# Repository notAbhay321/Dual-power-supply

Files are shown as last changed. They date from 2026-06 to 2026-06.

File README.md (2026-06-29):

# ESP32 Smart Automation — Regulated AC to DC Multi-Voltage Power Supply

A custom-designed regulated power supply that converts **230V AC mains** into stable **5V and 3.3V DC** outputs for ESP32-based smart automation systems (water tank management, irrigation control, etc.).

> **Total BOM Cost: ~₹583** | **Efficiency: 88–90%** | **Ripple: <30 mV**

---

## Hardware

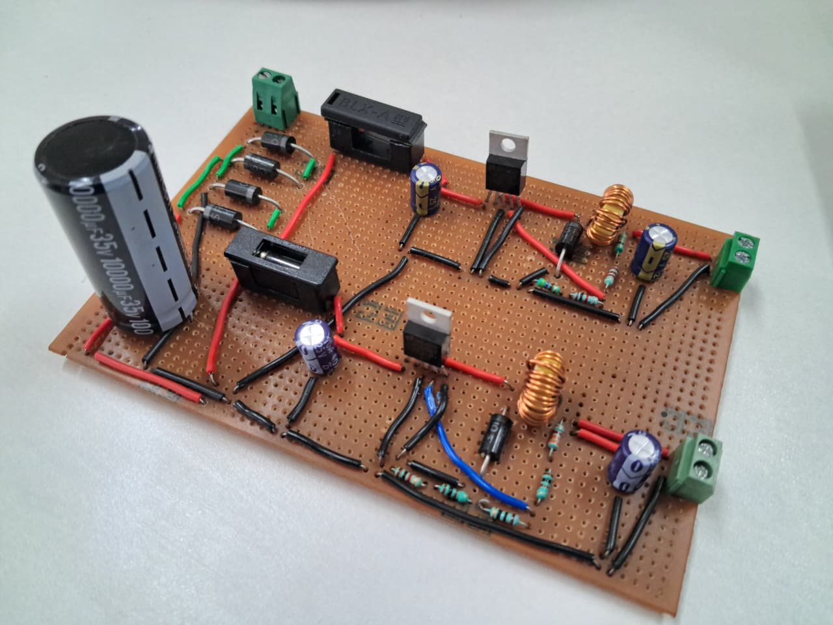
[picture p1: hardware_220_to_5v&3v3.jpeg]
Hardware PCB


*Assembled prototype — 230V AC to 5V & 3.3V regulated DC*

---

## Simulation Results

| 5V Output Rail | 3.3V Output Rail |
|:---:|:---:|
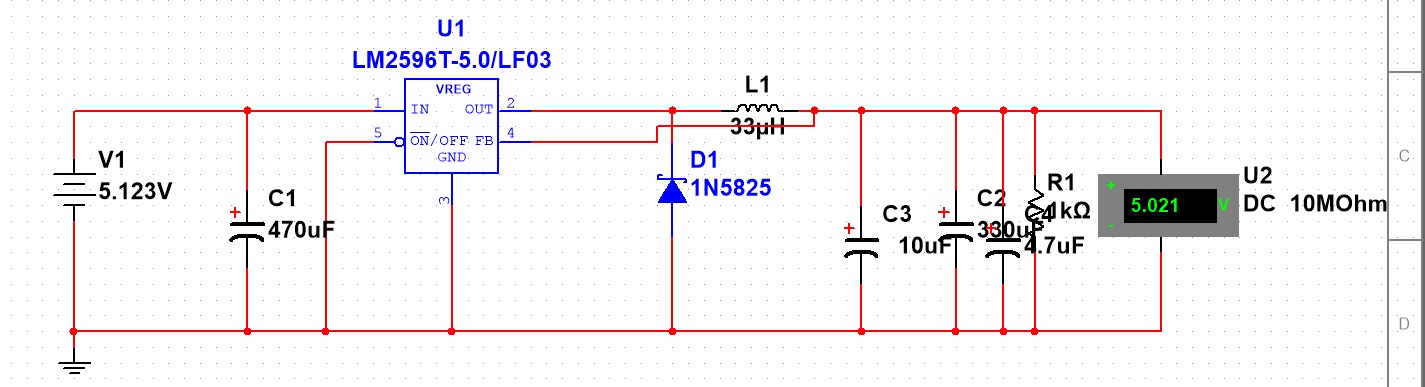
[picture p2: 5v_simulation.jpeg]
5V Simulation
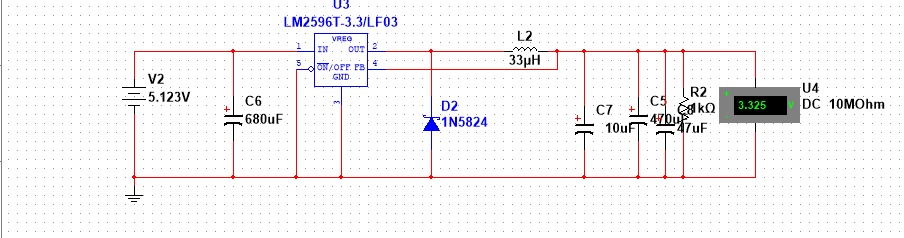
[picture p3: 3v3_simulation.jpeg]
3.3V Simulation
|  |  |

---

## Demo Video

▶️ [`output_video_5v and 3.3v.mp4`](output_video_5v%20and%203.3v.mp4) — Live measurement of both regulated outputs under load.

---

## Why This Project Exists

Off-the-shelf USB adapters and chargers fail in 24/7 automation scenarios because:

- They provide only one voltage rail
- They introduce electrical noise → sensors misread
- Voltage sags during ESP32 WiFi transmission → random controller resets
- They lack proper isolation from 230V AC (safety risk outdoors)

This project builds a **dedicated dual-rail power supply** that separates:
- **5V rail** → Relay modules, ultrasonic sensors
- **3.3V rail** → ESP32 controller, soil moisture sensors

---

## Key Specifications

| Parameter | Value |
|---|---|
| AC Input | 230V, 50Hz |
| DC Output 1 | 5V @ 2A |
| DC Output 2 | 3.3V @ 1A |
| Ripple Voltage | < 30 mV (3.3V rail) |
| Regulation IC | LM2596-ADJ (×2) |
| Efficiency | 88–90% |
| Isolation | Transformer-based galvanic isolation |

---

## System Overview

```
230V AC → Step-Down Transformer → Bridge Rectifier (SR560)
       → Filter Capacitors (10,000 µF)
       → LM2596 Buck #1 → 5V Rail  → Relays, Ultrasonic Sensor
       → LM2596 Buck #2 → 3.3V Rail → ESP32, Soil Moisture Sensor
```
### Full Block Diagram and Flowchart

<p align="center">
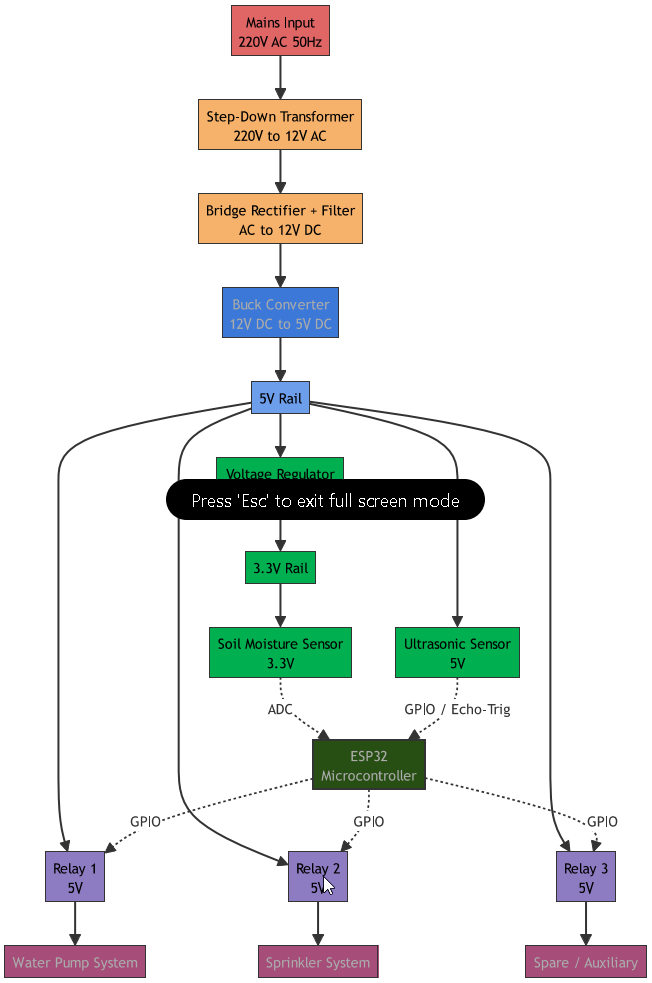
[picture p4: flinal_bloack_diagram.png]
Block diagram
  
</p>
---

## Repository Structure

```
esp32-power-supply/
├── README.md                         ← You are here
│
├── 5v_simulation.jpeg                ← 5V buck converter simulation output
├── 3v3_simulation.jpeg               ← 3.3V buck converter simulation output
├── hardware_220_to_5v&3v3.jpeg       ← Hardware prototype photo
├── output_video_5v and 3.3v.mp4      ← Live demo video
│
├── PowerSupply.ms14                  ← Main Multisim simulation (full circuit)
├── transformer_220v_9v.ms14          ← Transformer stage simulation
├── 220v_to_3v3_short_ckt_protection.ms14  ← Short circuit protection sim
│
├── ki_cad_pcb_power_supply/          ← KiCad PCB design files
├── datasheet/                        ← Component datasheets (LM2596, SR560, etc.)
│
├── docs/
│   ├── 01-introduction.md            ← Problem statement, motivation, objectives
│   ├── 02-literature-survey.md       ← Power supply topology review
│   ├── 03-system-design.md           ← Block diagram, flowchart, design decisions
│   ├── 04-calculations.md            ← Full component-level math
│   ├── 05-results.md                 ← Simulation + hardware results
│   └── 06-future-scope.md            ← Planned improvements
│
├── hardware/
│   ├── bom.md                        ← Bill of Materials with costs
│   └── component-selection.md        ← Why each component was chosen
│
├── simulation/
│   └── README.md                     ← How to open and run the .ms14 files
│
├── images/                           ← Additional diagrams and screenshots
├── LICENSE
```

---

## Quick Results

| Test Point | Measured Value |
|---|---|
| Transformer Secondary Output | ~14.1V AC |
| Rectified DC (after filter) | ~16V DC |
| Buck Converter Output 1 | **5.02V DC** |
| Buck Converter Output 2 | **3.31V DC** |
| Ripple (3.3V rail) | **< 30 mV** |
| Max Load (5V rail) | 2A stable |
| ESP32 WiFi peak handling | 250–500 mA, no resets |

---

## PCB Design

KiCad schematic and PCB layout files are in [`ki_cad_pcb_power_supply/`](ki_cad_pcb_power_supply/).
Open with **KiCad 9.0+**.

---

## Simulation Files

All simulations were built in **NI Multisim**. Open the `.ms14` files in Multisim 14+:

| File | What It Simulates |
|---|---|
| [`PowerSupply.ms14`](PowerSupply.ms14) | Full circuit — transformer → rectifier → both buck converters |
| [`transformer_220v_9v.ms14`](transformer_220v_9v.ms14) | Transformer stage only (220V → 9V AC) |
| [`220v_to_3v3_short_ckt_protection.ms14`](220v_to_3v3_short_ckt_protection.ms14) | Short circuit protection on 3.3V rail |

See [`simulation/README.md`](simulation/README.md) for setup instructions.

---

## License

MIT License — see [`LICENSE`](LICENSE)

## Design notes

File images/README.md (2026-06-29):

# Images

Additional diagrams and reference screenshots.

---

## What's in the Root (not this folder)

The main project visuals are stored at the **repository root** for easy GitHub rendering:

| File | Description |
|---|---|
| [`5v_simulation.jpeg`](../5v_simulation.jpeg) | 5V buck converter Multisim output |
| [`3v3_simulation.jpeg`](../3v3_simulation.jpeg) | 3.3V buck converter Multisim output |
| [`hardware_220_to_5v&3v3.jpeg`](../hardware_220_to_5v&3v3.jpeg) | Assembled PCB prototype photo |
| [`output_video_5v and 3.3v.mp4`](../output_video_5v%20and%203.3v.mp4) | Live demo — both rails measured under load |

---

## Suggested Additions to This Folder

If you want to add more visuals, drop them here and reference them in the relevant `docs/` file:

| Suggested Filename | What to Add |
|---|---|
| `block-diagram.png` | Screenshot of the functional block diagram |
| `flowchart.png` | Screenshot of the operational flowchart |
| `kicad-schematic.png` | Exported schematic from KiCad |
| `kicad-pcb-layout.png` | PCB layout top view from KiCad |
| `oscilloscope-ripple.jpg` | Oscilloscope screenshot showing <30mV ripple |
| `full-setup.jpg` | ESP32 + sensors + relays powered by this supply |

### How to reference from a doc

```markdown
![KiCad Schematic](../images/kicad-schematic.png)
```

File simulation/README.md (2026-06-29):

# Simulation

All simulations were created in **NI Multisim 14**. The `.ms14` files are in the root of the repository.

---

## Simulation Files

| File | Stage Simulated | Key Measurement |
|---|---|---|
| [`PowerSupply.ms14`](../PowerSupply.ms14) | Full circuit (transformer → rectifier → both buck converters) | 5V and 3.3V regulated outputs |
| [`transformer_220v_9v.ms14`](../transformer_220v_9v.ms14) | Transformer stage only | 220V AC → 9V AC step-down |
| [`220v_to_3v3_short_ckt_protection.ms14`](../220v_to_3v3_short_ckt_protection.ms14) | Short circuit protection on 3.3V rail | Current limiting behavior |

---

## How to Open

1. Install **NI Multisim 14.0** or later
2. Open any `.ms14` file directly: `File → Open`
3. Run transient analysis: `Simulate → Run` (or press **F5**)

---

## Simulation Screenshots

These were captured from the Multisim runs and are saved at the repo root:

**5V Buck Converter Output:**

5V Simulation

**3.3V Buck Converter Output:**

3.3V Simulation

---

## What Was Simulated

### 1. Transformer Stage (`transformer_220v_9v.ms14`)
- Input: 220V AC, 60Hz source
- Transformer ratio: 24.44:1 (220V → 9V AC)
- Output confirmed: ~9V AC sinusoidal waveform
- Verified: No distortion, correct step-down ratio

### 2. Full Power Supply (`PowerSupply.ms14`)
- Bridge rectifier (SR560 Schottky model) + 10,000 µF filter
- Two LM2596 buck converter stages with 33 µH inductors
- Feedback resistor networks set for 5V and 3.3V outputs
- Representative resistive loads on both rails

**Key results from simulation:**

| Test Point | Simulated Value |
|---|---|
| Rectified DC output | ~16V DC |
| 5V buck output | **5.02V** |
| 3.3V buck output | **3.31V** |
| Ripple (3.3V rail) | **< 30 mV** |

### 3. Short Circuit Protection (`220v_to_3v3_short_ckt_protection.ms14`)
- Simulates a short circuit event on the 3.3V output rail
- Validates that the LM2596's internal current limiting activates
- Confirms no damage to upstream components during a fault

---

## Simulation vs Hardware Comparison

| Parameter | Simulated | Hardware Measured |
|---|---|---|
| 5V output | 5.02V | ~5.0V |
| 3.3V output | 3.31V | ~3.3V |
| 3.3V ripple | < 30 mV | < 30 mV |
| 5V max current | 2A (modeled load) | 2A stable |

Simulation results closely matched hardware measurements. Minor deviations are expected due to ideal component models in Multisim (no PCB parasitics, ideal transformer coupling).

---

## Notes

- The LM2596 model in Multisim uses `LM2596T-5.0/LF03` and `LM2596T-3.3/LF03` (fixed voltage variants) as a behavioral reference. The ADJ variant's behavior matches when the feedback network is configured correctly per [`../docs/04-calculations.md`](../docs/04-calculations.md).
- `1N5824` / `1N5825` Schottky models are used as SR560 equivalents — electrically identical for simulation purposes.

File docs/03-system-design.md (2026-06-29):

# System Design

## Architecture Overview

The supply chain converts 230V AC mains into two regulated DC rails through four sequential stages:

```
[230V AC Mains]
      │
      ▼
[Step-Down Transformer]  ← Galvanic isolation + voltage reduction
      │  ~12V AC
      ▼
[Full-Bridge Rectifier]  ← SR560 Schottky diodes
      │  Pulsating DC
      ▼
[Filter Capacitors]      ← 10,000 µF bulk + 470 µF local
      │  ~16V DC (smoothed)
      ├──────────────────────────────────┐
      ▼                                  ▼
[LM2596-ADJ Buck #1]            [LM2596-ADJ Buck #2]
      │  5V @ 2A                         │  3.3V @ 1A
      ▼                                  ▼
[Relay Modules]              [ESP32 Microcontroller]
[Ultrasonic Sensor]          [Soil Moisture Sensor]
[Water Pump Control]
```

---

## Functional Block Diagram (Text)

```
AC Input (230V 50Hz)
  └─► Step-Down Transformer (220V → 12V AC)
        └─► Bridge Rectifier + Filter (AC → ~16V DC)
              ├─► LM2596 Buck Converter #1
              │     └─► 5V Rail
              │           ├─► Relay 1 (Water Pump)   [GPIO]─┐
              │           ├─► Relay 2 (Sprinkler)    [GPIO]─┤─► ESP32
              │           ├─► Relay 3 (Spare)        [GPIO]─┘
              │           └─► Ultrasonic Sensor (HC-SR04)
              │
              └─► LM2596 Buck Converter #2
                    └─► 3.3V Rail
                          ├─► ESP32 (VCC)
                          └─► Soil Moisture Sensor
```

---

## Design Alternatives Considered

A morphological analysis was done across four functional stages:

### Stage 1 — Step-Down / Isolation

| Option | Pros | Cons | Selected? |
|---|---|---|---|
| Step-down transformer | Safe galvanic isolation, robust | Bulky, heavier | ✅ Yes |
| Capacitive dropper | No isolation, cheaper | Dangerous for outdoor use | ❌ No |
| SMPS primary-side | Compact, efficient | Complex design, high EMI risk | ❌ No |

### Stage 2 — Rectification

| Option | Vf Drop | Speed | Selected? |
|---|---|---|---|
| 1N4007 silicon bridge | ~1.1V | Slow | ❌ No |
| SR560 Schottky bridge | ~0.5V | Fast | ✅ Yes |

SR560 selected for lower conduction losses and fast switching compatibility with SMPS stages.

### Stage 3 — Filtering

| Option | Capacitance | Notes | Selected? |
|---|---|---|---|
| 1000–2200 µF | Lower | More ripple at 2A load | ❌ No |
| 10,000 µF | Higher | Calculated minimum for 2V ripple at 2A | ✅ Yes |

### Stage 4 — Voltage Regulation

| IC | Type | Efficiency | Max Current | Heat | Selected? |
|----|---|---|---|---|---|
| IC 7805 | Linear | ~45% | 1A | Very High | ❌ No |
| AMS1117-3.3 | LDO | ~60–70% | 1A | Medium | ❌ No |
| MP1584 | Buck | ~92% | 3A | Very Low | ⚠️ Alternative |
| **LM2596-ADJ** | **Buck** | **88–90%** | **3A** | **Low** | ✅ **Yes** |

**Why LM2596 over MP1584:** LM2596 has a larger package, easier to hand-solder on dotted PCB, proven datasheet application circuit, and identical current rating at slightly lower cost.

---

## Operational Flowchart

```
START
  │
  ▼
230V AC Input Applied
  │
  ▼
Step-Down Transformer
(Isolation + Voltage Reduction to ~12V AC)
  │
  ▼
Bridge Rectifier (SR560)
(AC → Pulsating DC)
  │
  ▼
Filter Capacitors
(10,000 µF + 470 µF → Smooth DC ~16V)
  │
  ▼
LM2596 Buck Converter Stages
(Generate 5V and 3.3V)
  │
  ▼
Output Voltage Stable?
  ├── NO  → Fault (check components / overload)
  └── YES
        │
        ▼
Power Supplied to ESP32, Sensors & Relays
  │
  ▼
Continuous Operation (24/7)
  │
  ▼
END (Power removed)
```

---

## Safety Design Decisions

1. **Transformer isolation** — complete galvanic break between 230V mains and DC output; essential for outdoor/agricultural use
2. **Fuse on AC input** — protects against primary-side faults
3. **35V-rated capacitors** at 16V DC bus — 2× voltage headroom margin
4. **LM2596 internal thermal shutdown** — prevents damage on overload
5. **SR560 Schottky as freewheeling diode** — handles fast switching without thermal stress

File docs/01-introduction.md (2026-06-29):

# Introduction

## The Problem

Modern IoT-based automation systems — smart water tanks, irrigation controllers, home monitoring — rely on microcontrollers like the ESP32 running **24/7**. The most overlooked failure point in these systems isn't the software or the sensors. It's the power supply.

### Where Normal Adapters Fail

Most automation builds use whatever USB adapter is lying around. These fail in practice because:

- **Single voltage only** — ESP32 needs 3.3V; relays need 5V. You can't run both cleanly from one unregulated rail.
- **High ripple & noise** — Cheap adapters introduce electrical noise that corrupts ultrasonic and soil moisture sensor readings.
- **Insufficient current headroom** — ESP32 peaks at 250–500 mA during WiFi transmission. Under-rated adapters cause voltage sag, which causes random controller resets.
- **No galvanic isolation** — Outdoor automation (pumps, irrigation) requires safe separation from 230V mains. Most adapters skip this.

### The Core Gap

> Without a properly designed power supply, your automation system becomes unreliable — no matter how good the sensors or ESP32 code are.

---

## Motivation

Two specific use cases drove this design:

1. **Automated Water Tank Management** — Level sensing + pump control running all day. Any power glitch → pump runs dry or tank overflows. Both cause hardware damage.
2. **Smart Irrigation** — Soil moisture readings fed to a relay controlling a valve. Noisy power → wrong ADC readings → wrong watering decisions.

Both applications demand:
- Continuous, stable power (no sags, no resets)
- Separate clean rails for logic and actuators
- Safety isolation from mains

---

## Objectives

1. Design a **dual-output regulated power supply** providing stable 5V and 3.3V DC.
2. Use **LM2596-ADJ buck converter** stages for high efficiency and adequate current capacity.
3. Achieve **ripple < 30 mV** on the 3.3V logic rail to prevent sensor noise and controller resets.
4. Handle **peak ESP32 WiFi current loads** (250–500 mA) without voltage drop.
5. Ensure **galvanic isolation** from 230V AC mains via a step-down transformer.
6. Validate performance through simulation (Proteus/Multisim) and hardware prototype testing.

---

## Problem Statement

> Design and Implementation of a Regulated AC to DC Multi-Voltage Power Supply for ESP32-Based Smart Automation Systems.

---

## Scope

This project covers:
- AC mains input (230V, 50Hz) → regulated DC outputs (5V, 3.3V)
- Transformer-based isolation stage
- Full-bridge rectification and capacitor filtering
- Dual LM2596-ADJ buck converter regulation
- Validation for relay modules, ultrasonic sensors, soil moisture sensors, and ESP32

Out of scope:
- ESP32 firmware / automation logic
- PCB fabrication (prototype built on dotted PCB)
- Battery backup / solar integration (noted in future scope)

---

## Report Structure

| File | Contents |
|---|---|
| [`02-literature-survey.md`](02-literature-survey.md) | Review of power supply topologies |
| [`03-system-design.md`](03-system-design.md) | Block diagram, alternatives, flowchart |
| [`04-calculations.md`](04-calculations.md) | Component-level design calculations |
| [`05-results.md`](05-results.md) | Simulation and hardware test results |
| [`06-future-scope.md`](06-future-scope.md) | Future improvements and societal impact |
| [`../hardware/bom.md`](../hardware/bom.md) | Bill of Materials |
| [`../hardware/component-selection.md`](../hardware/component-selection.md) | Component selection rationale |

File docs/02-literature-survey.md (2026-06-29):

# Literature Survey

## Background

IoT automation platforms like the ESP32 require stable voltage with minimal noise for reliable wireless communication and accurate sensor readings. Poor power supply design is a leading cause of automation system failure. This survey reviews existing topologies and identifies the best fit for ESP32-based applications.

---

## Power Supply Topologies

### Linear Power Supplies

- Step down AC via transformer → rectify → filter → linear regulator
- **Pros:** Very low ripple, simple design, low noise
- **Cons:** Low efficiency (40–50% typical); excess voltage dropped as heat; bulky at high current
- **Verdict for IoT:** Unsuitable at 2A+ loads — too much heat, too little efficiency

### Switched Mode Power Supplies (SMPS)

- Use high-frequency switching to transfer energy efficiently
- **Pros:** 80–92% efficiency, compact, low thermal output
- **Cons:** Switching action introduces ripple and EMI; requires careful filtering
- **Verdict for IoT:** The right category — proper filtering makes it suitable

### Buck Converters

A specific SMPS topology for **step-down** conversion:
- Inductor stores energy during switch ON, releases during switch OFF
- Control loop maintains regulated output
- LM2596 series: popular in embedded/IoT for high efficiency and 3A current capability
- **Key design requirement:** Proper inductor and output capacitor selection to minimize ripple

### Linear Regulators (LDO)

- Regulate by dissipating excess voltage as heat
- Examples: 7805, AMS1117, LD1117
- **Pros:** Zero switching noise, simple circuit
- **Cons:** Efficiency depends on (Vout/Vin) ratio — poor at high input voltages; can't handle high current without large heatsinks
- **Verdict:** Useful as a post-regulator on a low-voltage rail; not as a primary 230V→5V stage

---

## ESP32 Power Requirements

The ESP32 is a dual-core MCU with integrated WiFi and Bluetooth. Key power characteristics:

| Parameter | Value |
|---|---|
| Operating Voltage | 3.3V |
| Typical current (idle) | 20–80 mA |
| Peak current (WiFi TX) | 250–500 mA |
| ADC reference sensitivity | Affected by supply noise |

**Implication:** The 3.3V rail must hold steady during 250–500 mA WiFi bursts. A supply that sags under load will cause the ESP32 to reset mid-operation.

### Full System Load Estimate

| Component | Current |
|---|---|
| 3× Relay Modules | ~250 mA |
| Ultrasonic Sensor (HC-SR04) | 15 mA |
| Soil Moisture Sensor | 10–20 mA |
| ESP32 WiFi Peak | 250–500 mA |
| **Total Estimated Load** | **600–800 mA** |

---

## Power Supply Requirements for IoT

### Voltage Stability
- Voltage variation must be < ±5% of nominal to avoid ESP32 brownout resets
- Transient response must recover quickly from sudden load steps (WiFi bursts)

### Noise and Ripple
- Switching supplies introduce ripple that corrupts ADC readings
- For the ESP32's 12-bit ADC: ripple should ideally be < 50 mV; < 30 mV is preferred
- Soil moisture and ultrasonic sensors are sensitive to power noise

### Efficiency
- 24/7 operation makes efficiency important for thermal management and electricity cost
- Linear regulators at 2A from a 12V input dissipate ~14W as heat — not viable

---

## Design Decision Based on Survey

The literature clearly supports a **switched-mode dual-output supply** as the best architecture:

| Criterion | Linear | LDO | Buck (LM2596) |
|---|---|-----|---|
| Efficiency | Low | Medium | High |
| Current Handling | Medium | Low | High (3A) |
| Ripple | Very Low | Low | Medium (filterable) |
| Thermal Performance | Poor | Medium | Good |
| Design Complexity | Low | Low | Medium |
| Cost | Low | Low | Medium |

**Selected approach:** Dual LM2596-ADJ buck converter stages — one for 5V, one for 3.3V — fed from a transformer-isolated rectified supply.

---

## References

- Espressif Systems, "ESP32 Series Datasheet," v4.0, 2023
- Texas Instruments, "LM2596 SIMPLE SWITCHER 150-kHz 3-A Step-Down Voltage Regulator," SNVS124D, 2016
- M. H. Rashid, *Power Electronics: Circuits, Devices, and Applications*, 4th ed., Pearson, 2014
- Vishay, "SR560 Schottky Barrier Rectifier Datasheet," Rev. 1.1, 2018
- S. Kumar and A. R. Al-Ali, "Power Management Strategies for IoT Nodes," IEEE Access, vol. 8, 2020
- Texas Instruments, "AN-1149 Layout Guidelines for Switching Power Supplies," SNVA021C, 2013

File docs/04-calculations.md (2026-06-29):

# Component-Level Design & Calculations

All calculations are based on worst-case load conditions to ensure reliable 24/7 operation.

---

## 1. Filter Capacitor Selection

**Goal:** Limit ripple voltage to ~2V at full load (2A) from a 50Hz full-wave rectifier.

**Formula (full-wave rectifier):**

```
C = I_load / (2 × f × V_ripple)
```

**Values:**
- I_load = 2A (maximum design load)
- f = 50 Hz (AC mains)
- V_ripple = 2V (allowed ripple at rectifier output)

**Calculation:**

```
C = 2 / (2 × 50 × 2)
C = 2 / 200
C = 0.01 F = 10,000 µF
```

**Selected:** 10,000 µF / 35V electrolytic capacitor.

> The 35V rating provides a 2× safety margin over the ~16V DC bus.

---

## 2. DC Voltage Analysis

Verifying the rectifier output provides enough headroom for the buck converters.

**Transformer secondary:** ~12V AC RMS
**Rectified peak voltage:**
```
V_peak = 12 × √2 − (2 × V_f_SR560)
       = 16.97 − (2 × 0.5)
       = 15.97V ≈ 16V DC
```

**Average DC voltage (after filtering):**
```
V_avg = V_peak − (V_ripple / 2)
      = 15.97 − 1.0
      = 14.97V
```

**Minimum DC voltage (worst case trough):**
```
V_min = V_peak − V_ripple
      = 15.97 − 2.0
      = 13.97V
```

**Conclusion:** Minimum 13.97V input to the buck converters. LM2596 requires at least Vout + 1.5V input headroom. For 5V output, minimum needed = 6.5V. ✅ Sufficient headroom confirmed.

---

## 3. Buck Converter Inductor Calculation (LM2596)

**Goal:** Keep inductor ripple current (ΔI_L) at ~30% of max load current for continuous conduction mode.

**Parameters:**
- V_in = 15V (conservative average)
- V_out = 5V
- f_sw = 150 kHz (LM2596 internal switching frequency)
- I_load_max = 2A
- ΔI_L = 30% × 2A = 0.6A

**Formula:**
```
L = (V_out × (V_in − V_out)) / (V_in × f_sw × ΔI_L)
```

**Calculation:**
```
L = (5 × (15 − 5)) / (15 × 150,000 × 0.6)
L = (5 × 10) / 1,350,000
L = 50 / 1,350,000
L ≈ 37 µH
```

**Selected:** 33 µH / 5A inductor (nearest standard value below calculated).

> The 5A current rating ensures no saturation even at peak transient loads.

---

## 4. Feedback Resistor Network (Output Voltage Setting)

The LM2596-ADJ sets output voltage via a resistor divider to Pin 4 (FB). Internal reference: **V_ref = 1.23V**.

**Formula:**
```
V_out = V_ref × (1 + R2/R1)
      = 1.23 × (1 + R2/R1)
```

### 5V Output Rail

**Target:** V_out = 5.0V

```
5.0 = 1.23 × (1 + R2/R1)
R2/R1 = (5.0/1.23) − 1 = 3.065
```

Using standard values:
- R1 = 1.085 kΩ → use **1.1 kΩ**
- R2 = 3.36 kΩ → use **3.3 kΩ**

**Verification:**
```
V_out = 1.23 × (1 + 3.36/1.085) = 1.23 × 4.095 ≈ 5.03V ✅
```

### 3.3V Output Rail

**Target:** V_out = 3.3V

```
3.3 = 1.23 × (1 + R2/R1)
R2/R1 = (3.3/1.23) − 1 = 1.683
```

Using standard values:
- R1 = 1.48 kΩ → use **1.5 kΩ**
- R2 = 2.5 kΩ → use **2.5 kΩ**

**Verification:**
```
V_out = 1.23 × (1 + 2.5/1.48) = 1.23 × 2.689 ≈ 3.31V ✅
```

---

## 5. Freewheeling Diode Selection

When the LM2596 internal switch opens, the inductor's collapsing magnetic field generates a large back-EMF spike. A fast freewheeling (flyback) diode is required to clamp this.

**Why not 1N4007?**
- Reverse recovery time: ~30 µs — far too slow for 150 kHz switching
- At 150 kHz, the 1N4007 would cause shoot-through current and major heat dissipation

**Selected: SR560 Schottky Diode**

| Parameter | 1N4007 | SR560 |
|---|---|---|
| Forward voltage (V_f) | ~1.1V | ~0.5V |
| Reverse recovery | ~30 µs | ~10 ns |
| Max current | 1A | 5A |
| Switching compatibility | No (too slow) | ✅ Yes |

Power loss comparison at 2A:
```
P_1N4007 = 1.1V × 2A = 2.2W (wasted as heat)
P_SR560  = 0.5V × 2A = 1.0W (55% reduction)
```

---

## 6. Input/Output Capacitor Selection

### Input Capacitor (at LM2596 Vin pin)
- **Value:** 470 µF / 25V
- **Purpose:** Buffers sudden current demand during ESP32 WiFi transmission bursts (250–500 mA spikes)
- Prevents voltage starving the LM2596 during fast load transients

### Output Capacitors
- **Primary output:** 470 µF / 25V (bulk)
- **Secondary decoupling:** 10 µF + 47 µF (reduces high-frequency switching ripple)
- Combined low-ESR network improves load transient response

---

## Summary of Selected Values

| Component | Calculated | Selected |
|---|---|---|
| Filter capacitor | 10,000 µF | 10,000 µF / 35V ✅ |
| Inductor | 37 µH | 33 µH / 5A ✅ |
| R1 (5V rail) | 1.085 kΩ | 1.1 kΩ ✅ |
| R2 (5V rail) | 3.36 kΩ | 3.3 kΩ ✅ |
| R1 (3.3V rail) | 1.48 kΩ | 1.5 kΩ ✅ |
| R2 (3.3V rail) | 2.5 kΩ | 2.5 kΩ ✅ |
| Freewheeling diode | Schottky, fast | SR560 ✅ |
| Input capacitor | 470 µF | 470 µF / 25V ✅ |

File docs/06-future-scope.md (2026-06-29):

# Future Scope

The current design is a functional, tested prototype. Several improvements are planned for future versions.

---

## Planned Enhancements

### 1. EMI Shielding and Layout Optimization
The LM2596 switching at 150 kHz generates electromagnetic interference that can affect the ESP32's ADC on long signal wires. Future revisions should:
- Move to a proper PCB with a ground plane
- Add a ferrite bead on the 3.3V output rail
- Use shorter, thicker traces for high-current paths
- Add an EMI filter on the AC input (common-mode choke + X/Y capacitors)

### 2. Power Telemetry via ESP32
Add real-time monitoring of the supply itself:
- INA219 current sensor IC on the 5V and 3.3V rails
- Report voltage, current, and power to an MQTT broker or a local web dashboard
- Alert when voltage drops below safe thresholds (brownout prediction)

### 3. Adaptive Power Management
- Implement sleep mode synchronization between the ESP32 and the power supply
- During low-activity periods (no sensor polling, no relay switching), throttle the system to reduce thermal load on filter capacitors
- Extend electrolytic capacitor lifespan by reducing average ripple current

### 4. PCB Miniaturization
- Migrate from dotted PCB to a compact two-layer PCB
- Target form factor: < 80mm × 60mm
- Place decoupling capacitors physically close to LM2596 pins (reduces switching noise)

### 5. Battery Backup
- Add a LiPo/Li-Ion charge management stage (TP4056 or BQ24195)
- Automatic switchover when mains power fails
- Keeps the ESP32 running during power outages (important for water pump control)

### 6. Solar / Off-Grid Support
- Replace transformer stage with a solar charge controller input
- Add MPPT (Maximum Power Point Tracking) for 12V solar panel input
- Enables deployment in farms without grid access

### 7. Enhanced Protection Circuits
- TVS diode on AC input (surge suppression)
- Auto-resetting polyfuse instead of glass fuse
- Reverse polarity protection on DC outputs
- Overcurrent latch with LED fault indicator

---

## Societal Impact

A reliable power supply directly enables the automation of water-critical systems:

| Application | Impact |
|---|---|
| Smart water tank | Prevents overflow (water waste) and pump dry-run (motor damage) |
| Precision irrigation | Accurate soil moisture → correct watering → better crop yield |
| Home automation | Lower maintenance cost; fewer hardware failures |
| Agricultural IoT | Enables off-grid automation with solar extension |

Stable power infrastructure is foundational to IoT-based resource conservation. By ensuring sensors and controllers operate correctly, this design supports reduced water usage, lower electricity bills, and improved reliability in both urban and rural automation contexts.

---

## Conclusion Summary

| Objective | Status |
|---|---|
| Stable 5V @ 2A output | ✅ Achieved |
| Stable 3.3V @ 1A output | ✅ Achieved |
| Ripple < 30 mV on 3.3V rail | ✅ Achieved |
| Handle ESP32 WiFi peak (250–500 mA) | ✅ No resets observed |
| Galvanic isolation from 230V | ✅ Transformer-based |
| 24/7 continuous operation | ✅ Stable in testing |
| Cost under ₹600 | ✅ ~₹583 total BOM |

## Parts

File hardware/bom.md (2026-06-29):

# Bill of Materials (BOM)

All components are available in Indian electronics markets (local or online via Robu, Rajiv, Amazon).

**Total Estimated Cost: ₹583**

---

## Component List

| # | Component | Specification | Qty | Unit Cost (₹) | Total (₹) | Where Used |
|---|---|---|-----|---|---|---|
| 1 | Step-Down Transformer | 230V AC → 12V AC, 2A | 1 | 250 | 250 | AC isolation + step-down |
| 2 | SR560 Schottky Diode | 5A, 60V | 4 | 15 | 60 | Bridge rectifier |
| 3 | LM2596-ADJ Buck Converter IC | 3A, 150kHz | 2 | 35 | 70 | 5V and 3.3V regulation |
| 4 | Electrolytic Capacitor | 10,000 µF / 35V | 1 | 70 | 70 | Bulk filter (rectifier output) |
| 5 | Electrolytic Capacitor | 470 µF / 25V | 2 | 10 | 20 | Buck converter input filter |
| 6 | Electrolytic Capacitor | 10 µF / 25V | 2 | 5 | 10 | Output smoothing |
| 7 | Electrolytic Capacitor | 47 µF / 25V | 2 | 5 | 10 | Output smoothing |
| 8 | Inductor | 33 µH / 5A | 1 | 43 | 43 | Buck converter energy storage |
| 9 | Resistors (various) | 1.1kΩ, 3.3kΩ, 1.5kΩ, 2.5kΩ | Several | ~1 each | 10 | Feedback voltage dividers |
| 10 | Dotted PCB Board | ~10cm × 8cm | 1 | 40 | 40 | Prototype assembly |
| 11 | Fuse + Holder | 2A, 250V | 1 | 20 | 20 | AC input protection |
| **Total** | | | | | **₹603*** | |

*Actual BOM assembled for ~₹583 with local pricing.*

---

## Key Component Notes

### LM2596-ADJ (×2)
- Handles 3A continuous with minimal heatsinking
- Adjustable output via feedback resistor network
- Built-in thermal shutdown and current limiting
- Available: Robu.in, local electronics shops
- **Do not substitute with LM2596-5.0 fixed version** — the ADJ variant is needed to set exact voltages

### SR560 Schottky Diode (×4)
- Used in bridge rectifier configuration (×4 for full-bridge)
- Also used as freewheeling diode in each buck converter stage
- Lower Vf (0.5V) vs 1N4007 (1.1V) → less heat at 2A
- Must be Schottky for 150 kHz compatibility in freewheeling role

### 33 µH / 5A Inductor
- Critical: current rating must be **≥ 5A** to prevent saturation
- Common mistake: using a 33 µH / 1A or 2A inductor — will saturate and fail
- Check: inductor should not get hot at 2A load; if it does, check saturation current spec

### 10,000 µF / 35V Capacitor
- Physically large — plan PCB space accordingly
- **Must be rated ≥ 25V**; 35V provides safety margin
- ESR should be low (< 0.1Ω); standard electrolytic is fine at 50Hz ripple frequency

---

## Where to Buy (India)

| Source | Suitable For |
|---|---|
| Robu.in | LM2596, inductors, Schottky diodes |
| Rajiv Components (Bangalore) | Transformers, capacitors, resistors |
| Amazon India | Most ICs and passives |
| Local electronics market | Transformers, PCB boards, fuses |

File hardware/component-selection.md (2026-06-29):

# Component Selection Rationale

This document explains the reasoning behind each major component choice. For calculations that supported these decisions, see [`../docs/04-calculations.md`](../docs/04-calculations.md).

---

## Voltage Regulator: LM2596-ADJ (vs. alternatives)

| Feature | IC 7805 | AMS1117-3.3 | MP1584 | **LM2596-ADJ** |
|---|---|---|---|---|
| Type | Linear | LDO | Buck | Buck |
| Max current | 1A | 1A | 3A | **3A** |
| Efficiency | ~45% | ~60–70% | ~92% | **~88–90%** |
| Heat at 2A | Very high (~14W) | High | Very low | **Low (~1.5W)** |
| Package size | TO-220 (easy) | SOT-223 (small) | SOP-8 (tiny) | **TO-263 (easy)** |
| Hand-solderable | ✅ | ✅ | ⚠️ (small pads) | ✅ |
| Cost | ₹25 | ₹20 | ₹90 | **₹35** |

**Decision:** LM2596-ADJ selected over MP1584 despite marginally lower efficiency because:
1. Larger package is easier to hand-solder on dotted PCB
2. Well-documented application circuit in TI datasheet
3. Better price/performance than MP1584 for this current range
4. Built-in thermal shutdown reduces risk of damage

**IC 7805 rejected** because at 2A from 16V input, it dissipates (16-5)×2 = 22W — requires a massive heatsink, and is thermally impractical for 24/7 operation.

---

## Rectifier Diode: SR560 (vs. 1N4007)

**Why Schottky over standard silicon:**

| Property | 1N4007 | SR560 |
|---|---|---|
| Forward voltage (Vf) | ~1.1V | ~0.5V |
| Reverse recovery time | ~30 µs | ~10 ns |
| Max current | 1A | 5A |
| Power loss at 2A | 2.2W | 1.0W |

- Lower Vf → more voltage available to the buck converters
- Fast recovery → essential for the freewheeling diode role at 150 kHz
- Higher current rating → same diode used in both bridge and freewheeling positions, simplifying procurement

---

## Inductor: 33 µH / 5A (vs. calculated 37 µH)

The calculated minimum inductance was 37 µH. Standard inductor values near this are 33 µH and 47 µH.

**Why 33 µH was chosen over 47 µH:**
- 33 µH → slightly higher ripple current (0.66A vs 0.53A) — both are in continuous conduction mode
- 33 µH is more commonly stocked; 47 µH in 5A rating is harder to find
- At 5A current rating, either value handles peak load without saturation

**Critical requirement:** Current rating must be ≥ 5A. A 33 µH / 1A inductor (common in small modules) will saturate immediately at 2A load and fail.

---

## Filter Capacitor: 10,000 µF / 35V

**Why 10,000 µF:** Calculated minimum for 2V ripple at 2A from 50Hz supply. Smaller values increase ripple, which reduces minimum input voltage to the buck converters.

**Why 35V rating:** The rectified peak voltage is ~16V DC. Component datasheets recommend derating capacitors to 50–70% of rated voltage for longevity. 35V / 16V = 2.2× derating — well within the safe range.

**Alternative considered:** Two 4700 µF capacitors in parallel (9400 µF total) — acceptable if a single 10,000 µF isn't available, but the single large capacitor is preferred for lower ESR.

---

## Transformer: 12V AC, 2A

**Why 12V secondary:**
- After rectification: ~16V DC peak
- Provides adequate headroom for both 5V and 3.3V buck converter inputs
- Step-down ratio keeps rectifier and capacitor voltage ratings manageable

**Why not use a 9V transformer:**
- 9V AC rectified = ~11.7V peak
- After Schottky drop (1V) and ripple trough (2V): minimum ~8.7V
- Still sufficient, but less margin for line voltage variation

**Why not use a 15V transformer:**
- 15V AC rectified = ~20V peak
- Slightly more heat in the LM2596, higher voltage stress on capacitors
- 12V is the sweet spot for this application

**Transformer provides galvanic isolation** — the single most important safety feature for mains-connected automation in outdoor/agricultural environments.

---

## PCB: Dotted PCB (Prototype Stage)

A dotted (perforated) PCB was used for the prototype. For production or next revision, a proper two-layer PCB is recommended with:
- Dedicated ground plane
- Short, wide traces for high-current paths (≥ 2mm for 2A)
- Decoupling capacitors placed physically adjacent to IC pins
- Thermal relief pads for the transformer and LM2596 pins

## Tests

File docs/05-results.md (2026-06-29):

# Results and Discussion

Validation was done in two phases: simulation first, then hardware prototype testing.

---

## Phase 1: Simulation

**Tools used:** Proteus, NI Multisim

The simulation model included:
- 230V AC source → transformer model
- SR560 bridge rectifier + 10,000 µF filter capacitor
- Two LM2596-ADJ buck converter stages
- 33 µH inductor and SR560 freewheeling diode
- Representative load resistors matching ESP32 + relay current draw

### Transformer Stage

The step-down transformer correctly reduced 220V AC to ~12V AC secondary output. Waveform confirmed proper sinusoidal shape with no distortion.

### Rectifier and Filter Output

After the SR560 bridge rectifier and 10,000 µF filter capacitor:
- Rectified DC: **~16V**
- Ripple at rectifier output: within calculated 2V budget

### Buck Converter Outputs

| Stage | Target | Simulated Output |
|---|---|---|
| Buck #1 | 5V | **5.02V** |
| Buck #2 | 3.3V | **3.31V** |

Both outputs were stable under varying load conditions.

**5V Rail:**
5V Simulation

**3.3V Rail:**
3.3V Simulation

### Ripple Analysis

| Rail | Ripple Voltage |
|---|---|
| 5V rail | < 50 mV |
| 3.3V rail | **< 30 mV** ✅ |

The 33 µH inductor smoothed switching current effectively. SR560 freewheeling diode reduced conduction losses compared to standard silicon diodes.

### Simulation Summary Table

| Test Point | Observed Value |
|---|---|
| Transformer secondary | ~14.1V AC |
| Rectified output | ~16V DC |
| Buck #1 output | 5.02V DC |
| Buck #2 output | 3.31V DC |
| Ripple (3.3V rail) | < 30 mV |

---

## Phase 2: Hardware Prototype

The prototype was built on a dotted PCB board. Components soldered manually.

Hardware Prototype

*Assembled PCB — full circuit from 230V AC input to 5V and 3.3V regulated outputs.*

### Setup

- Step-down transformer (230V → 12V AC)
- SR560 Schottky bridge rectifier
- 10,000 µF / 35V filter capacitor
- Two LM2596-ADJ buck converter stages
- 33 µH / 5A inductor
- Feedback resistor networks (5V and 3.3V configurations)
- Additional output capacitors: 470 µF, 10 µF, 47 µF

### Measured Results

| Parameter | Measured |
|---|---|
| 5V rail output | ~5.0V |
| 5V rail max current | 2A stable |
| 3.3V rail output | ~3.3V |
| 3.3V rail max current | 1A stable |
| Ripple (3.3V rail) | < 30 mV |
| ESP32 WiFi peak handled | 250–500 mA without voltage drop |
| Thermal behavior | No overheating at continuous load |
| Controller resets during WiFi TX | None observed |

### Observations

- The 10,000 µF bulk capacitor effectively buffered load transients from ESP32 WiFi bursts
- SR560 diodes ran cooler than equivalent 1N4007 diodes would have at 2A (lower Vf)
- Both buck converter outputs remained stable within ±50 mV under varying load
- No heatsink required on LM2596 at tested loads (thermal shutdown not triggered)
- System ran continuously without failures during testing

---

## Discussion

### Did simulation match hardware?

Yes, within acceptable margins. Simulated ripple (<30 mV) matched hardware measurements. Voltage outputs were within ±1% of target.

### Efficiency comparison

At 2A output, 5V rail:

| Regulator | Efficiency | Heat at 2A |
|---|---|---|
| IC 7805 (linear) | ~45% | ~14W |
| LM2596 (buck) | ~88–90% | ~1.5W |

The LM2596 choice eliminated the need for heatsinking and made continuous operation practical.

### Key takeaway

A well-filtered switching supply with a dedicated 3.3V rail delivers clean, stable power that off-the-shelf adapters cannot. The ESP32 ran without a single reset during WiFi-heavy testing — the primary failure mode of cheap adapter builds.

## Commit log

2026-06-29 final simulation
    final dual power supply simulation
2026-06-29 pcb image
2026-06-29 Enhance README.md with additional sections and formatting
    Updated the README.md to improve formatting, add sections for hardware, simulation results, demo video, PCB design, and team roles.
2026-06-29 updated readme.md file
    Added detailed project documentation for the ESP32 Smart Automation power supply, including specifications, simulation results, and repository structure.
2026-06-29 Add full block diagram and flowchart section
    Added a section for the full block diagram and flowchart with an image.
